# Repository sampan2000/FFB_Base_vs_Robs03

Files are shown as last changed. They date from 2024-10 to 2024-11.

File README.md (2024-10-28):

# FFB_Base_vs_Robs03使用灵足03电机的FFB底座
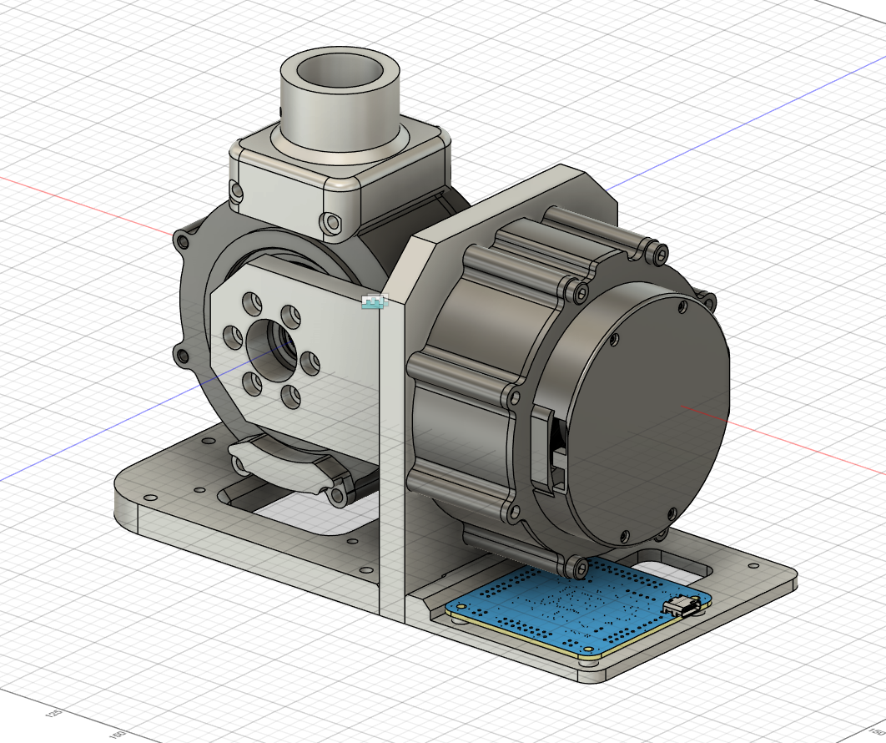
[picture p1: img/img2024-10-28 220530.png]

灵足03电机额定扭矩20nm，峰值60nm，非常够劲，即使加上25cm延长杆，峰值也能达到3kg杆力。
考虑到电机力矩较大，主要结构件使用铝合金CNC加工，为了满足<a href="https://gy2025.com/#/home/proofing">铨洲</a>打样的要求，把结构件拆成了4个单独的件。改了两个版本，目前已经用了半个多月了，结构基本上没啥问题，CNC加工成本大概100出头。
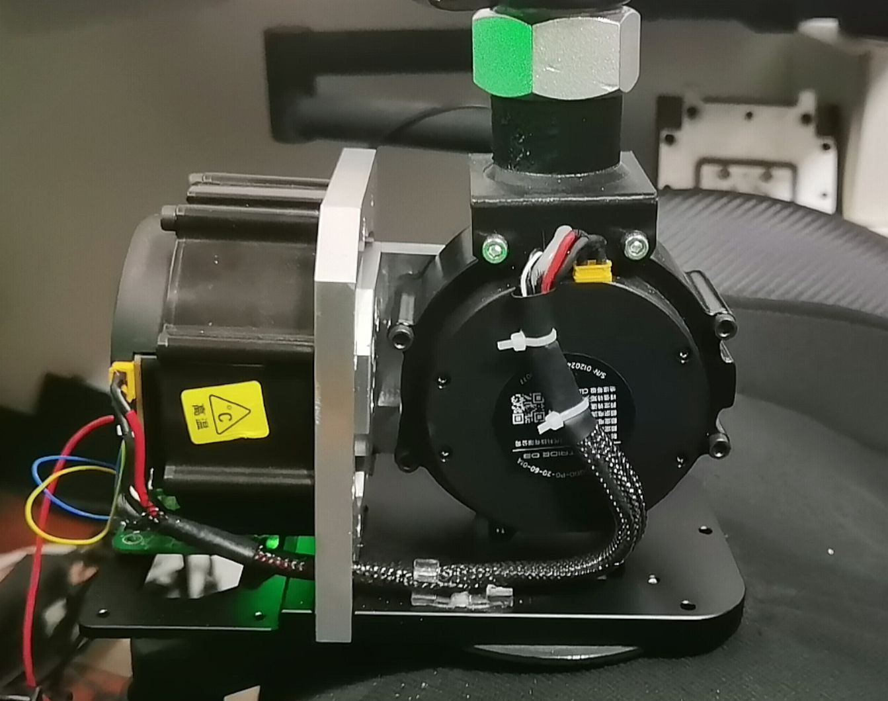
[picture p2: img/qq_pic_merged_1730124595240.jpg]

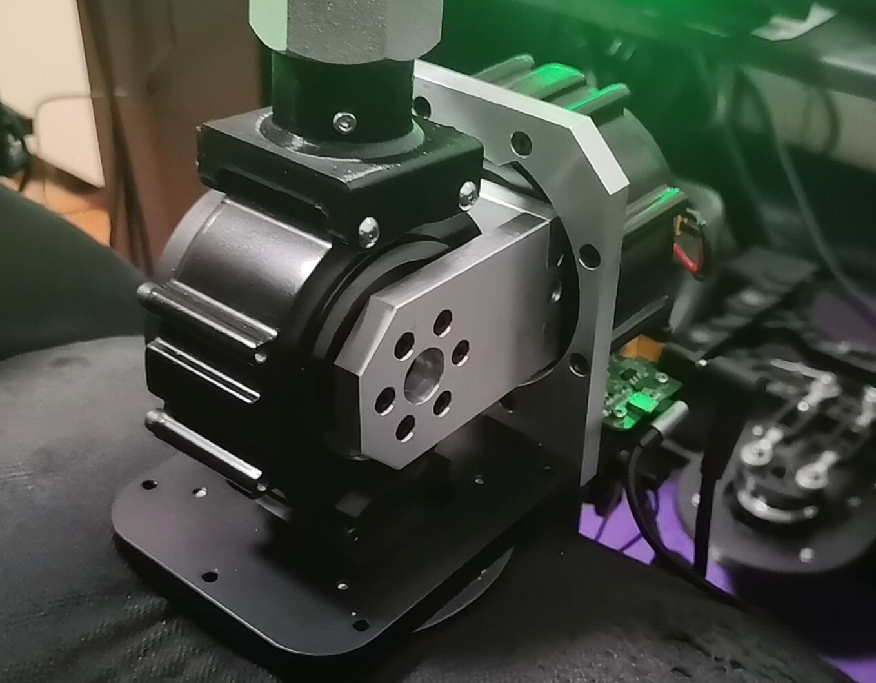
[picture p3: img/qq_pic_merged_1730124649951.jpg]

需要注意一下，因为铨洲CNC 6.8打样还不支持侧孔，所以打样的时候需要把下面图上的3个孔去掉，回来以后手工打孔攻丝（M4）
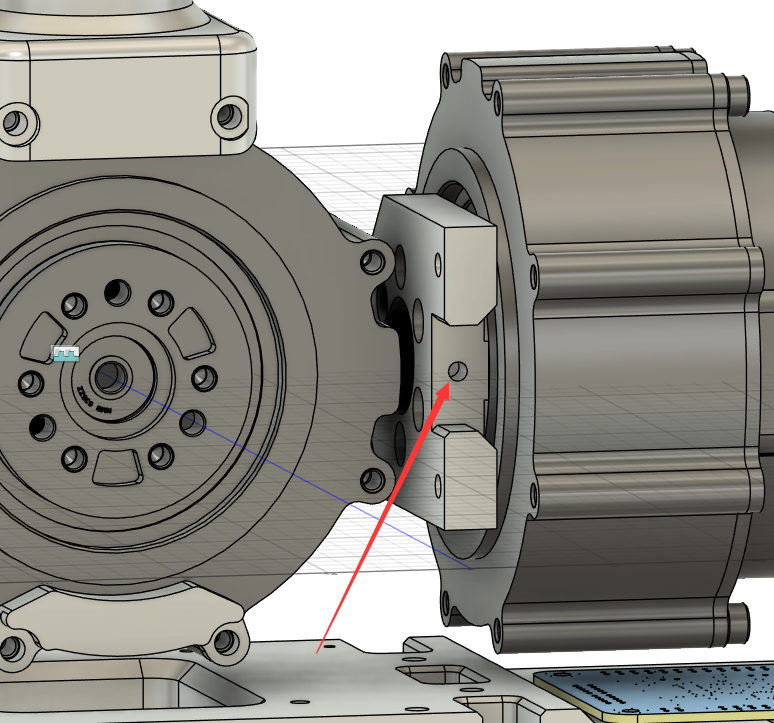
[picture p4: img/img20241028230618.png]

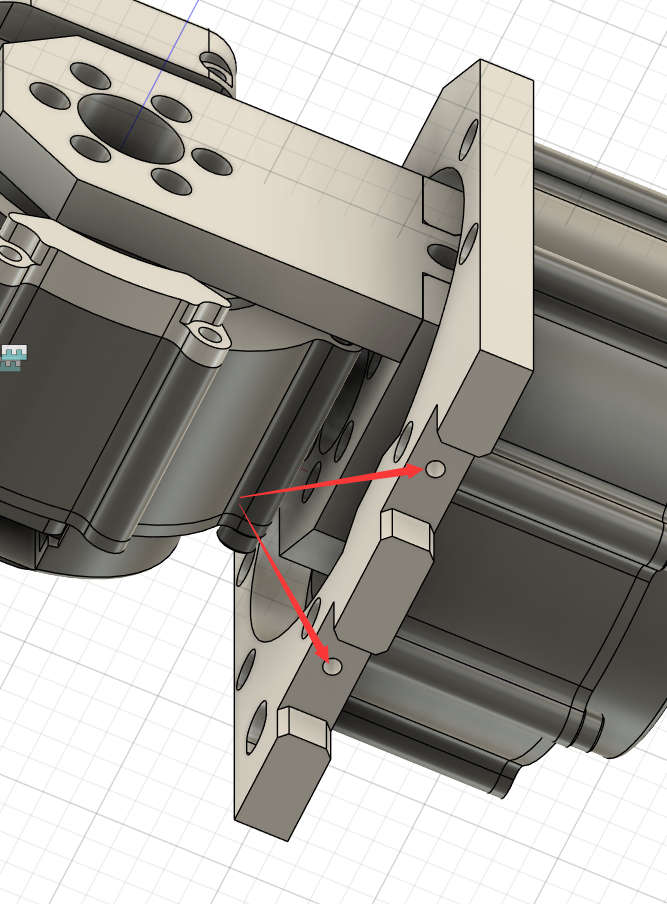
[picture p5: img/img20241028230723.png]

其余需要攻丝的孔都按铨洲攻丝的要求画的，可以充分利用铨洲每个件免费攻丝8个孔的便宜。
另外画了一外壳，装上以后宽度比成都造天秤座还窄一点。不过感觉太丑了，先不放上来了，等我再改改。
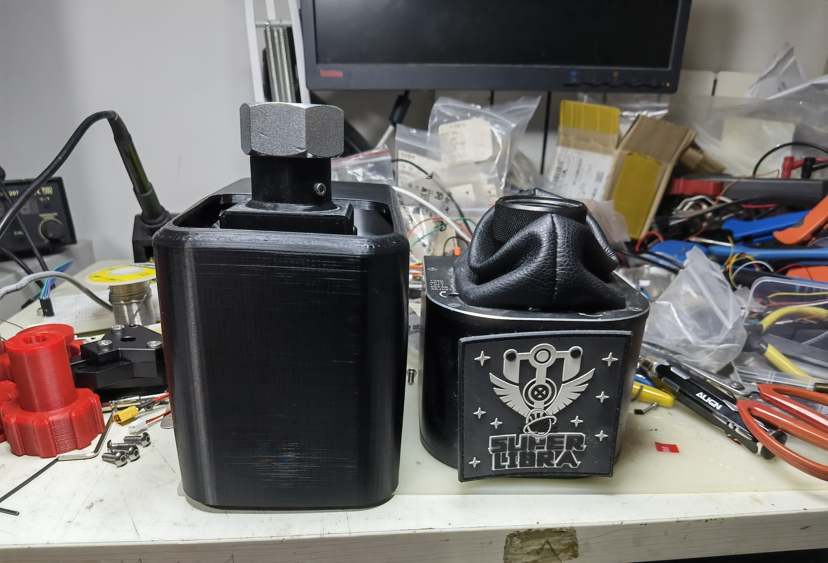
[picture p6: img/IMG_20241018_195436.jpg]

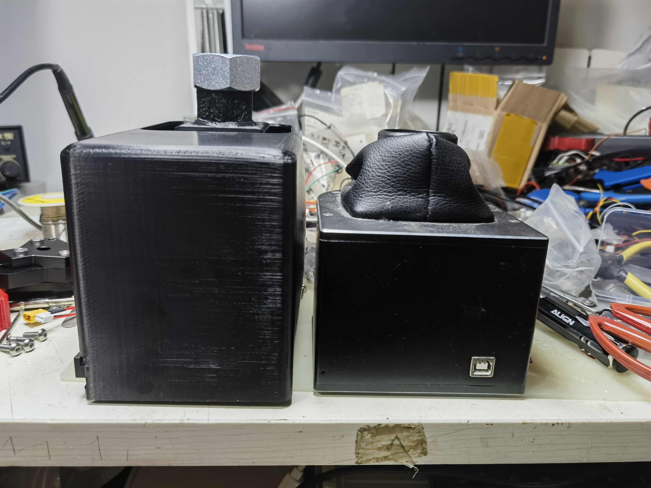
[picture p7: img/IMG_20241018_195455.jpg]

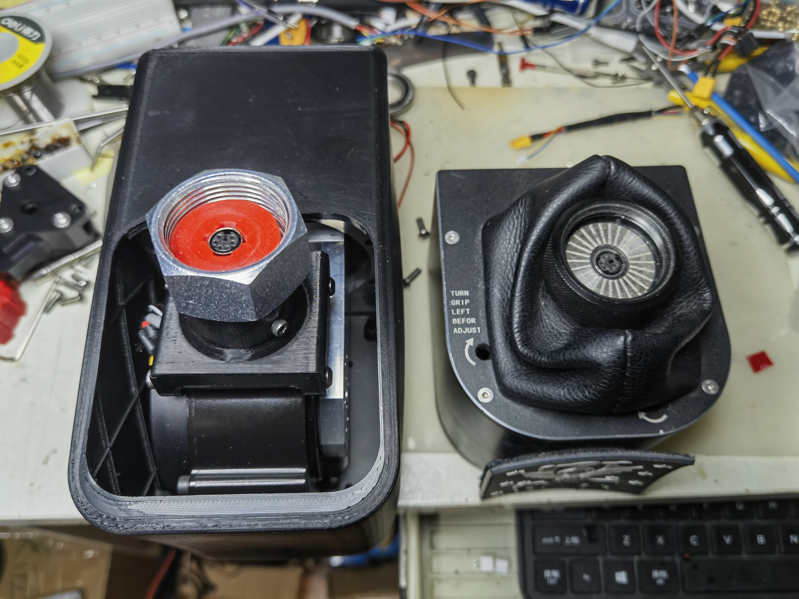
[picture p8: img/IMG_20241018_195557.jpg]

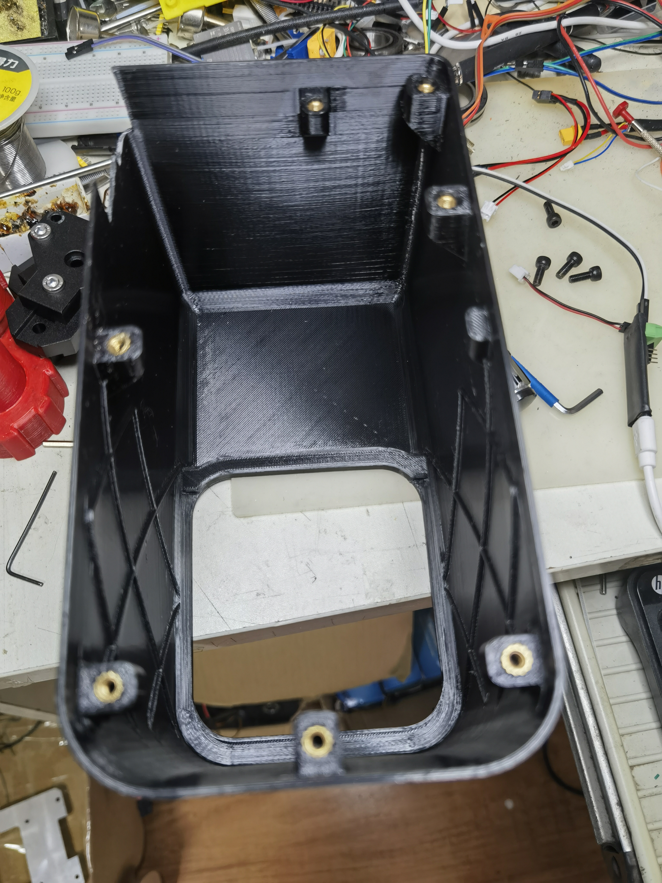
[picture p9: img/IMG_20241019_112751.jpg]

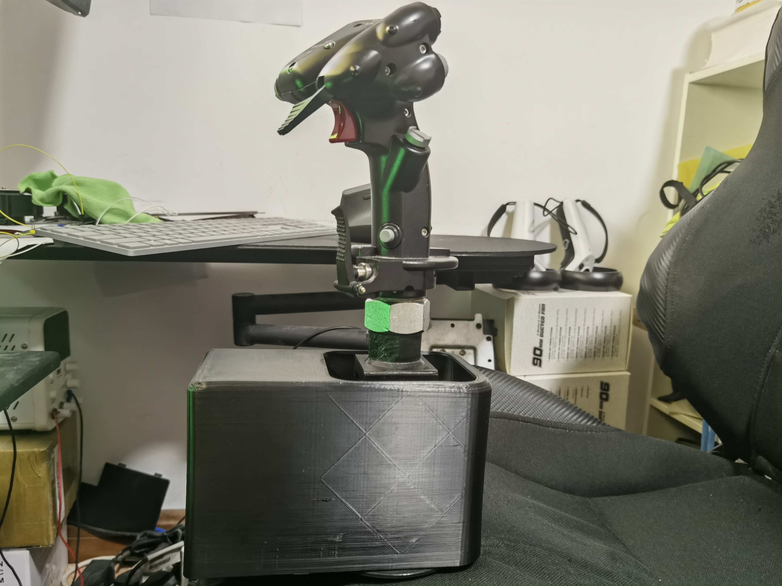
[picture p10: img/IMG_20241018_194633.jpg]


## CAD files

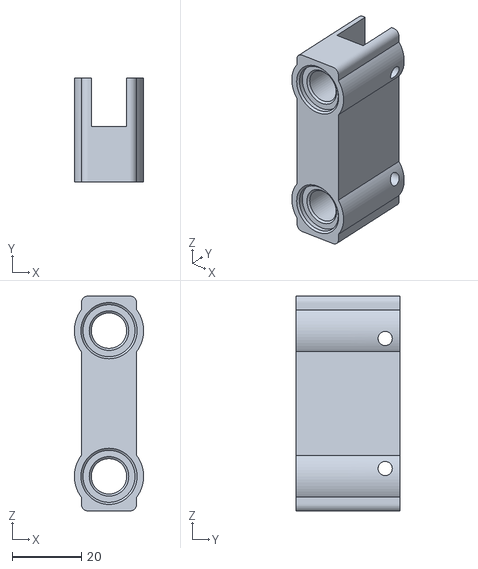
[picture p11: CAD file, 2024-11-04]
stl/治具3.stl
20.0 x 30.0 x 62.0

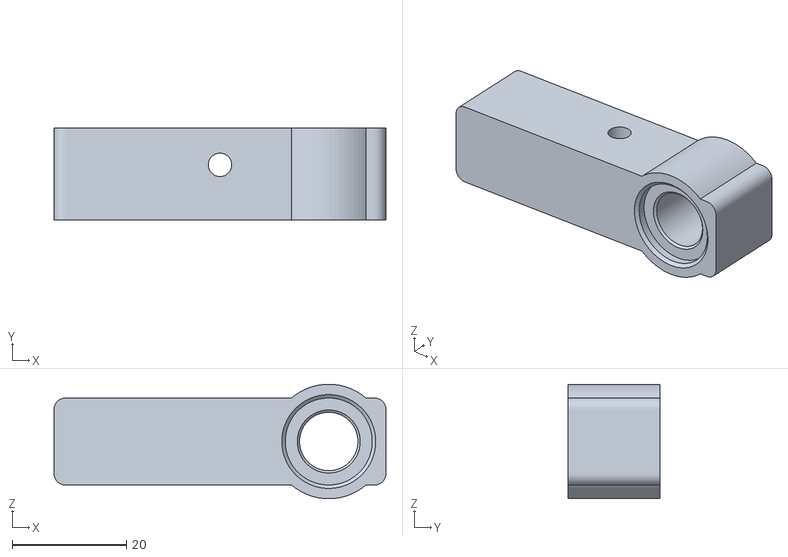
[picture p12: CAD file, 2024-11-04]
stl/治具2.stl
58.0 x 16.0 x 20.0

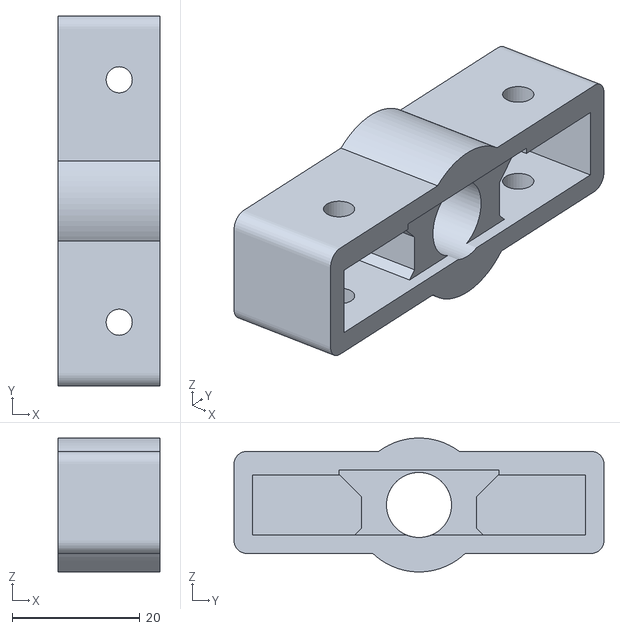
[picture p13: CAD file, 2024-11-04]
stl/治具1.stl
16.0 x 58.0 x 21.0

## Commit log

2024-10-28 初始提交
2024-11-04 增加了侧孔开孔用的治具
    没有台钻开孔容易打歪，打印的治具可以辅助手电钻打孔
    [治具1.stl, 治具2.stl, 治具3.stl]
2024-11-06 补充了两个漏掉的侧孔
    铨洲可以加工侧孔了
